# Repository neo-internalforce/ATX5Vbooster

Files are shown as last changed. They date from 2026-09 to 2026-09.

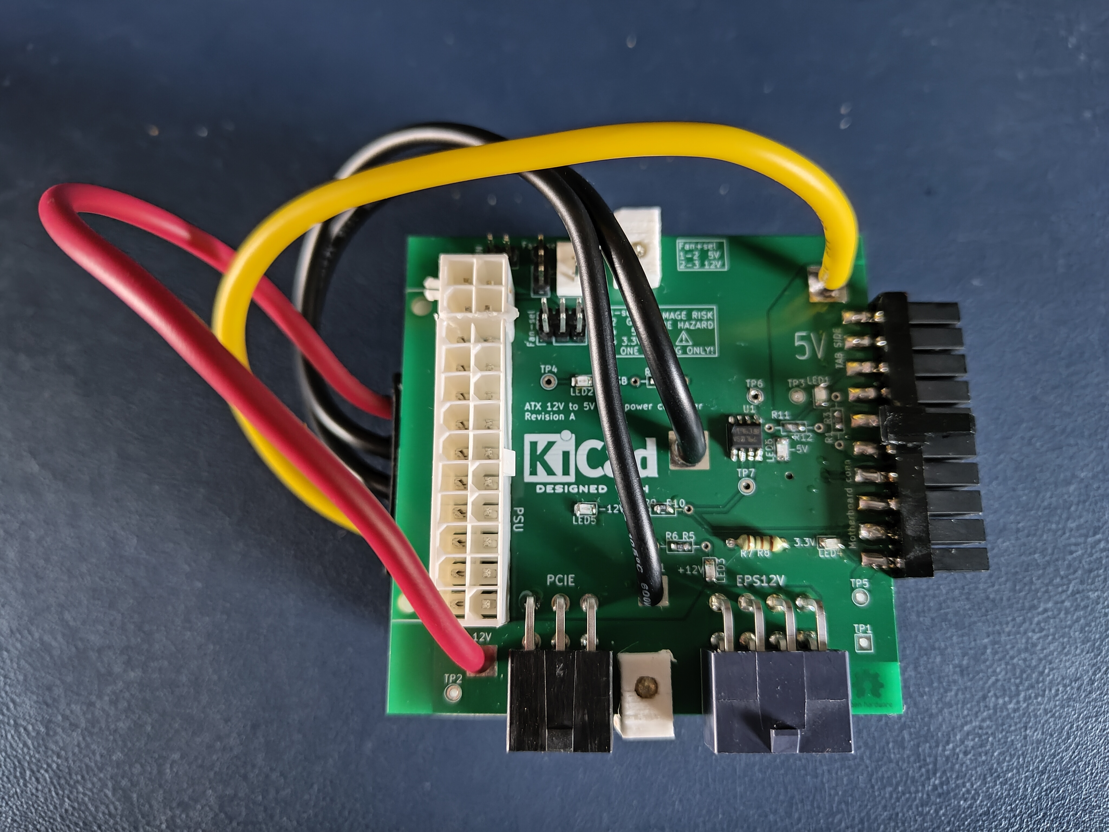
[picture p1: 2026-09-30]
Pictures/IMG_20260929_165454521.jpg

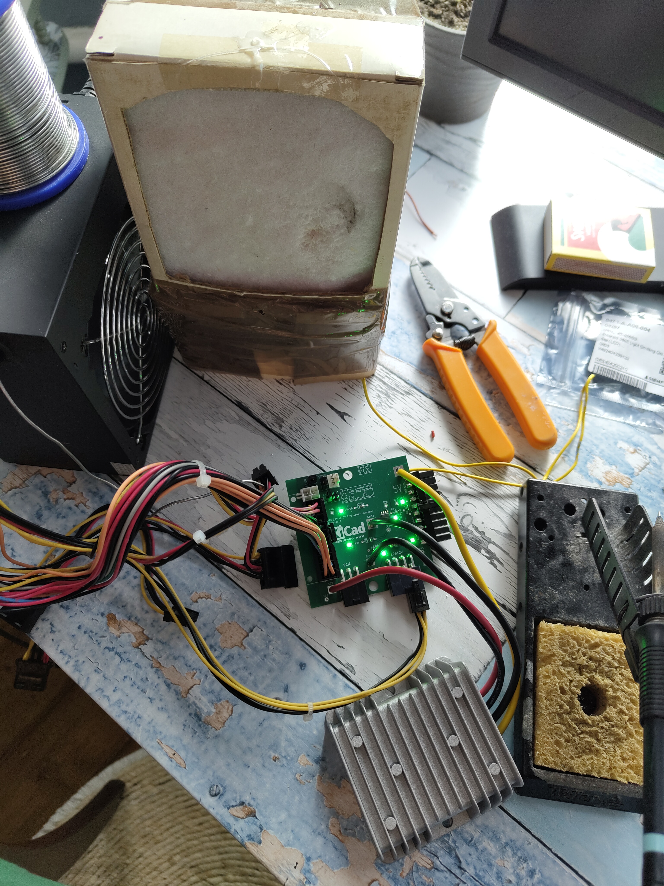
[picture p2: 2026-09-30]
Pictures/IMG_20260928_110612569.jpg

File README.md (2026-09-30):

# ATX5Vbooster
An interface board enabling powering 5V heavy 90s/00s PC motherboards with modern ATX power supplies (DCDC conversion from 12V input)
Watch the video (https://www.youtube.com/watch?v=BrJlWmi3LqU)

Snag list:
LEDs too bright - increase resistor values
Fitting into a motherboard might be problematic - consider an ATX extension lead
Thickness of the DCDC converter gets in the way

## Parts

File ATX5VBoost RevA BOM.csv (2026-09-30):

Reference | Qty | Value | DNP | Footprint | Datasheet | Description
5V1,GND2 | 2 | Wire |  | Connector_Wire:SolderWire-4sqmm_1x01_D3mm_OD6mm |  | To DCDC module
12V1,GND1 | 2 | Wire |  | Connector_Wire:SolderWire-2.5sqmm_1x01_D2.4mm_OD4.4mm |  | To DCDC module
EPS12V1 | 1 | 1724480008 |  | SamacSys_Parts:1724480008 | https://www.molex.com/en-us/products/part-detail-pdf/1724480008?display=pdf
Fan+sel1 | 1 | Conn_01x03_Pin |  | Connector_PinHeader_2.54mm:PinHeader_1x03_P2.54mm_Vertical
Fan-sel2 | 1 | Conn_02x03_Odd_Even |  | Connector_PinHeader_2.54mm:PinHeader_2x03_P2.54mm_Vertical
J3 | 1 | Conn_01x03 |  | Connector:FanPinHeader_1x03_P2.54mm_Vertical
LED1,LED2,LED3,LED4,LED5,LED6 | 6 | LED_Small |  | LED_SMD:LED_0805_2012Metric_Pad1.15x1.40mm_HandSolder
MOBO1 | 1 |  |  | SamacSys_Parts:ATX20pinEDGE |  | from AliExpress
PCIE1 | 1 | 649006227222 |  | SamacSys_Parts:649006227222 | https://katalog.we-online.de/em/datasheet/6490xx227222.pdf
PSU1 | 1 | 649024227222 |  | SamacSys_Parts:649024227222 | https://www.we-online.com/components/products/datasheet/649024227222.pdf
PS_ON1 | 1 | Conn_01x02 |  | Connector_PinHeader_2.54mm:PinHeader_1x02_P2.54mm_Vertical
R1,R2,R12 | 3 | 240R |  | Resistor_SMD:R_0603_1608Metric_Pad0.98x0.95mm_HandSolder
R3,R4,R11 | 3 | 240R | DNP | Resistor_THT:R_Axial_DIN0204_L3.6mm_D1.6mm_P7.62mm_Horizontal |  | Resistor
R5,R10 | 2 | 1K | DNP | Resistor_THT:R_Axial_DIN0204_L3.6mm_D1.6mm_P7.62mm_Horizontal |  | Resistor
R6,R9 | 2 | 1K |  | Resistor_SMD:R_0603_1608Metric_Pad0.98x0.95mm_HandSolder |  | Resistor
R7 | 1 | 100R |  | Resistor_THT:R_Axial_DIN0204_L3.6mm_D1.6mm_P7.62mm_Horizontal |  | Resistor
R8 | 1 | 100R | DNP | Resistor_SMD:R_0603_1608Metric_Pad0.98x0.95mm_HandSolder
TP1 | 1 | GND |  | TestPoint:TestPoint_THTPad_2.0x2.0mm_Drill1.0mm |  | test point
TP2 | 1 | 12V |  | TestPoint:TestPoint_THTPad_D2.0mm_Drill1.0mm |  | test point
TP3 | 1 | 5V |  | TestPoint:TestPoint_THTPad_D2.0mm_Drill1.0mm |  | test point
TP4 | 1 | +5VSB |  | TestPoint:TestPoint_THTPad_D2.0mm_Drill1.0mm |  | test point
TP5 | 1 | 3.3V |  | TestPoint:TestPoint_THTPad_D2.0mm_Drill1.0mm |  | test point
TP6 | 1 | -5V |  | TestPoint:TestPoint_THTPad_D2.0mm_Drill1.0mm |  | test point
TP7 | 1 | -12V |  | TestPoint:TestPoint_THTPad_D2.0mm_Drill1.0mm |  | test point
U1 | 1 | MC79L05_SO8 |  | Package_SO:SOIC-8_3.9x4.9mm_P1.27mm | http://www.ti.com/lit/ds/symlink/lm79l.pdf | -5V regulator IC

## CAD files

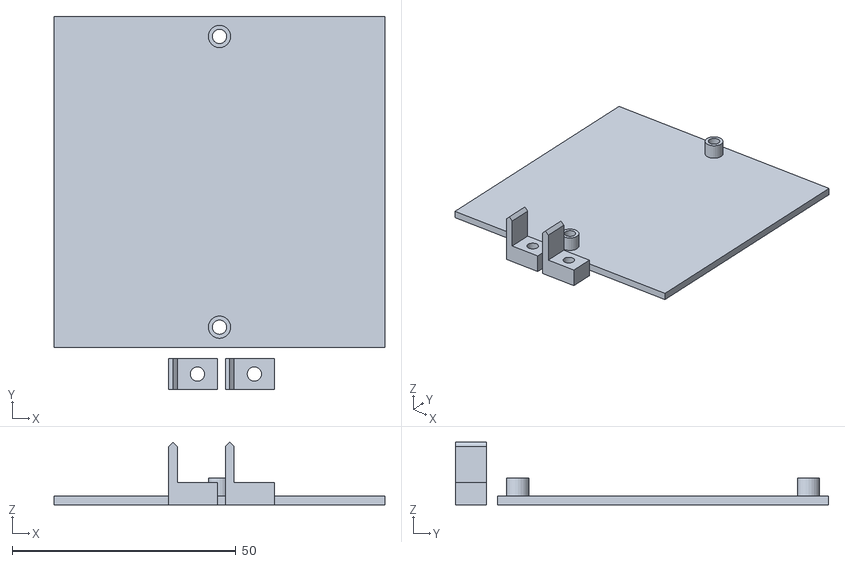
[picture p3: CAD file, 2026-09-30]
3D print models/DCDC spacer.stl
74.0 x 83.5 x 14.0

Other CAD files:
3D print models/DCDC spacer.skp

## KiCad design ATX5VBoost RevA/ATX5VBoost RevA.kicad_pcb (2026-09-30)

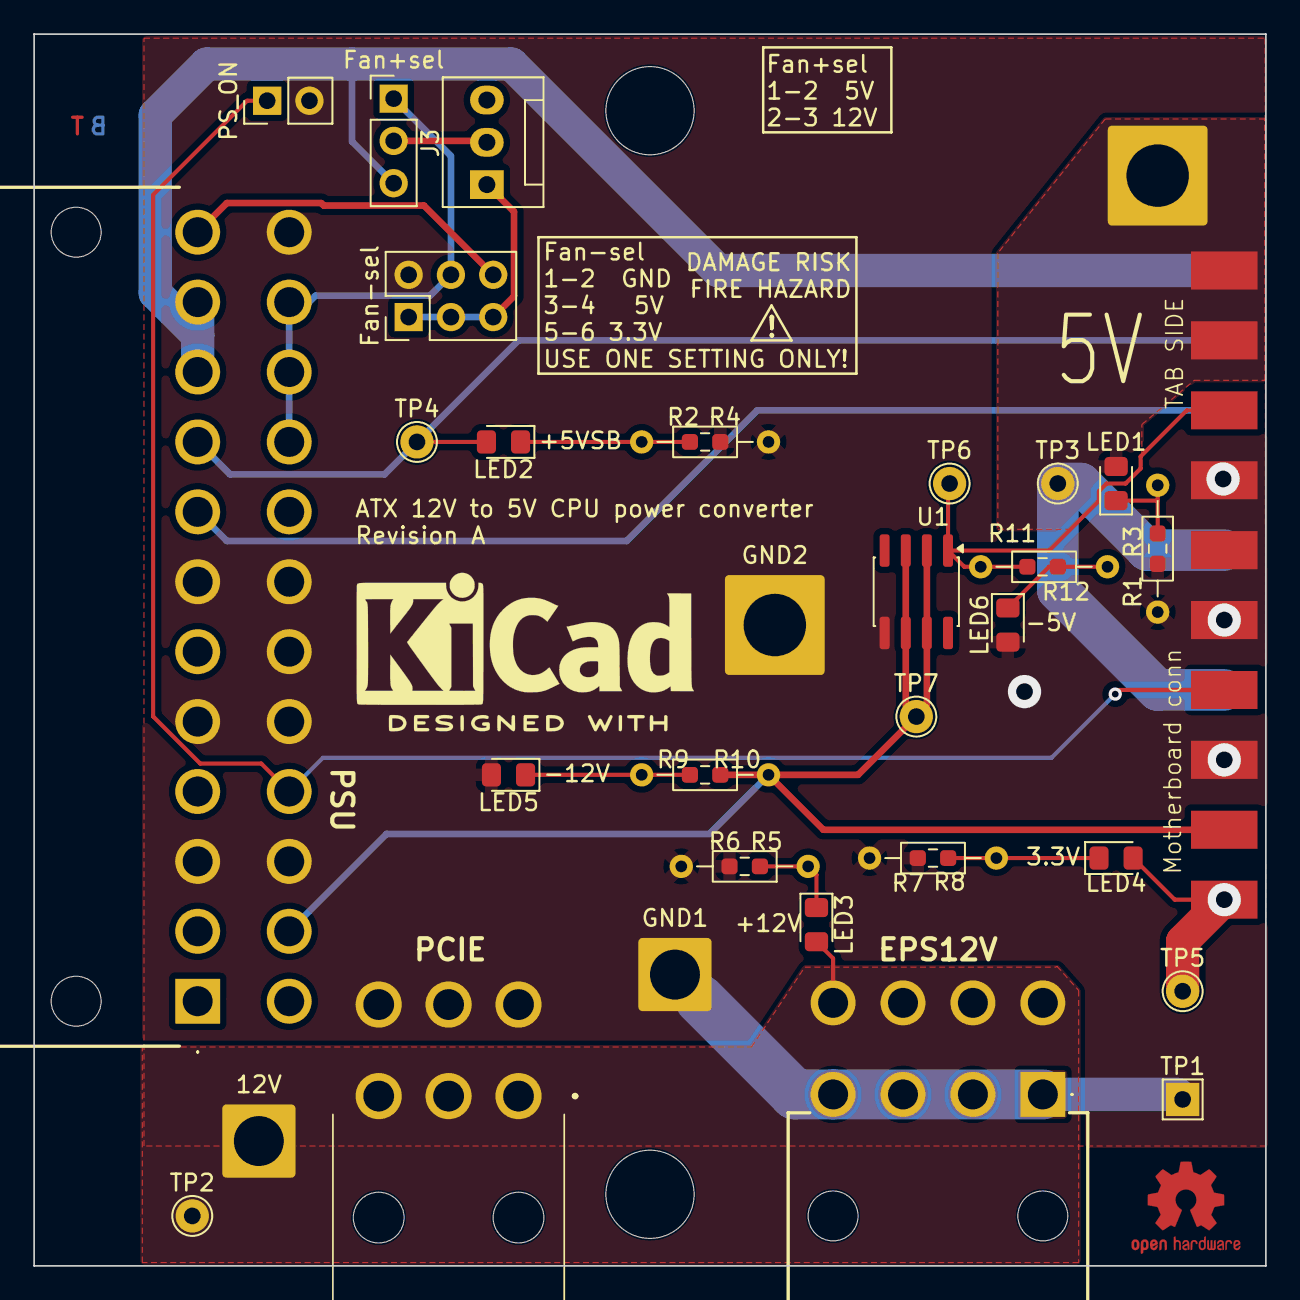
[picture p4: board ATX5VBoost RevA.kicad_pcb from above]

Board: 2 copper layers, 74.0 x 74.0 mm, 38 parts (0 on the bottom side), 19 nets.

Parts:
5V: Wire; SolderWire-4sqmm_1x01_D3mm_OD6mm
12V: Wire; SolderWire-2.5sqmm_1x01_D2.4mm_OD4.4mm
EPS12V: 1724480008
Fan+sel: Conn_01x03_Pin; PinHeader_1x03_P2.54mm_Vertical
Fan-sel: Conn_02x03_Odd_Even; PinHeader_2x03_P2.54mm_Vertical
GND1: Wire; SolderWire-2.5sqmm_1x01_D2.4mm_OD4.4mm
GND2: Wire; SolderWire-4sqmm_1x01_D3mm_OD6mm
J3: Conn_01x03; FanPinHeader_1x03_P2.54mm_Vertical
LED1, LED2, LED3, LED4, LED5, LED6: LED_Small; LED_0805_2012Metric_Pad1.15x1.40mm_HandSolder
Motherboard conn: ATX20pinEDGE
PCIE: 649006227222
PSU: 649024227222
PS_ON: Conn_01x02; PinHeader_1x02_P2.54mm_Vertical
R1, R2, R12: 240R; R_0603_1608Metric_Pad0.98x0.95mm_HandSolder
R3, R4, R11: 240R; R_Axial_DIN0204_L3.6mm_D1.6mm_P7.62mm_Horizontal
R5, R10: 1k; R_Axial_DIN0204_L3.6mm_D1.6mm_P7.62mm_Horizontal
R6: 1K; R_0603_1608Metric_Pad0.98x0.95mm_HandSolder
R7: 100R; R_Axial_DIN0204_L3.6mm_D1.6mm_P7.62mm_Horizontal
R8: 100R; R_0603_1608Metric_Pad0.98x0.95mm_HandSolder
R9: 1k; R_0603_1608Metric_Pad0.98x0.95mm_HandSolder
TP1: GND; TestPoint_THTPad_2.0x2.0mm_Drill1.0mm
TP2: 12V; TestPoint_THTPad_D2.0mm_Drill1.0mm
TP3: 5V; TestPoint_THTPad_D2.0mm_Drill1.0mm
TP4: +5VSB; TestPoint_THTPad_D2.0mm_Drill1.0mm
TP5: 3.3V; TestPoint_THTPad_D2.0mm_Drill1.0mm
TP6: -5V; TestPoint_THTPad_D2.0mm_Drill1.0mm
TP7: -12V; TestPoint_THTPad_D2.0mm_Drill1.0mm
U1: MC79L05_SO8; SOIC-8_3.9x4.9mm_P1.27mm

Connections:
+3.3V: Fan-sel.6, LED4.2 (A), Motherboard conn.1 (+3.3V), Motherboard conn.2 (+3.3V), Motherboard conn.11 (+3.3V), PSU.1 (3V3), PSU.2 (3V3), PSU.12 (3V3), PSU.13 (3V3), TP5.1 (1_1)
+5V: 5V.1 (Pin_1_1), LED1.2 (A), Motherboard conn.4 (+5V), Motherboard conn.6 (+5V), Motherboard conn.19 (+5V), Motherboard conn.20 (+5V), TP3.1 (1_1)
+12VA: 12V.1 (Pin_1_1), EPS12V.5, EPS12V.6, EPS12V.7, EPS12V.8, LED3.2 (A), PCIE.1, PCIE.2, PCIE.3, TP2.1 (1_1)
GND: EPS12V.1, EPS12V.2, EPS12V.3, EPS12V.4, Fan-sel.2, GND1.1 (Pin_1_1), GND2.1 (Pin_1_1), LED5.2 (A), LED6.2 (A), Motherboard conn.3 (COM), Motherboard conn.5 (COM), Motherboard conn.7 (COM), Motherboard conn.13 (COM), Motherboard conn.15 (COM), Motherboard conn.16 (COM), Motherboard conn.17 (COM), PCIE.4, PCIE.5, PCIE.6, PSU.3 (GND), PSU.5 (GND), PSU.7 (GND), PSU.15 (GND), PSU.17 (GND), PSU.18 (GND), PSU.19 (GND), PSU.24 (GND), PS_ON.2, R1.2, R2.2, R3.2, R4.2, R5.2, R6.2, R7.2, R8.2, TP1.1 (1_1), U1.5 (GND)
unnamed: Fan+sel.1, Fan-sel.4, PSU.21 (5V), PSU.22 (5V), PSU.23 (5V)
unnamed: Fan+sel.2, J3.2
unnamed: Fan+sel.3, Motherboard conn.10 (+12V), PSU.10 (12V), PSU.11 (12V)
unnamed: Fan-sel.1, Fan-sel.3, Fan-sel.5, J3.1
unnamed: LED1.1 (K), R1.1, R3.1
unnamed: LED2.2 (A), Motherboard conn.9 (+5VSB), PSU.9 (+5VSB), TP4.1 (1_1)
unnamed: LED2.1 (K), R2.1, R4.1
unnamed: LED3.1 (K), R5.1, R6.1
unnamed: LED4.1 (K), R7.1, R8.1
unnamed: LED5.1 (K), R9.1, R10.1
unnamed: LED6.1 (K), R11.1, R12.1
unnamed: Motherboard conn.18 (-5V), R11.2, R12.2, TP6.1 (1_1), U1.1 (OUT)
unnamed: Motherboard conn.12 (-12V), PSU.14 (-12V), R9.2, R10.2, TP7.1 (1_1), U1.2 (IN), U1.3 (IN), U1.6 (IN), U1.7 (IN)
unnamed: Motherboard conn.14 (PS_ON#), PSU.16 (PS_ON), PS_ON.1
unnamed: Motherboard conn.8 (PWR_OK), PSU.8 (PGOOD)

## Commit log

2026-09-30 Initial release
    As the first built prototype
    [ATX5VBoost RevA BOM.csv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]
2026-09-30 Initial release
    1st prototype build
    [DCDC spacer.skp, DCDC spacer.stl]
